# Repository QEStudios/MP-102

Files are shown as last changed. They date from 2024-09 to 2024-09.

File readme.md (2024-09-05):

# MP-102 Macropad

The MP-102 Macropad features 10 MX-compatible keys and 2 rotary encoders with optional buttons. It uses a Raspberry Pi Pico (RP2040) or compatible microcontroller as the brains. It can be constructed by anyone as long as you have a 3D printer.

## Ordering parts

The MP-102 was designed to be built on a budget of around $35 Australian Dollars. Thus, parts were aquired from less reliable places than where you might normally buy them. I've linked the relevant places here as well as in the `Layout and BOM.xlsx` file, but all of the parts are generic and can be bought from wherever you find easiest (or cheapest).

I ordered the Hot Melt Inserts from the link provided quite a while before I started this project, so I didn't personally factor this cost into the price of my own build of the MP-102.

[All prices in Australian Dollars]
| Item | Price | Link |
|---|---|---|
| 5pcs Rotary Encoder | $5.27 | https://www.aliexpress.com/item/1005003070250718.html |
| 10pcs Keycaps | $4.17 | https://www.aliexpress.com/item/1005005825113345.html |
| 10pcs Key Switches | $4.61 | https://www.aliexpress.com/item/1005006376024657.html |
| Raspberry Pi Pico | $4.32 | https://www.aliexpress.com/item/1005006293406528.html |
| 10pcs Hotswap Sockets | $2.65 | https://www.aliexpress.com/item/1005006737039916.html |
| M2 OD3.5 Holt Melt Inserts | $5.93 | https://www.aliexpress.com/item/1005006465779940.html |
| USB C Cable | $2.39 | https://www.aliexpress.com/item/1005006065386047.html |
| PCB | $5.20 | https://jlcpcb.com/ |

## Build Instructions

### 3D Prints

All 3D model files can be found in the `3D Models` folder in this repository.

You might want to first print out `USB C Test Piece.stl` and make sure that your USB cable fits through the hole, as this is the size of the opening to the USB C port on the Pico.

There are two different files for the knobs, one with 0.1mm tolerences and one with 0.2mm tolerences. I recommend printing both and choosing the one which fits better for you. You can also use the horizontal expansion setting in your slicer to fine-tune this to your liking.

All files (excluding `USC C Test Piece.stl`) need to be printed only once, apart from the knob file (either `Knob 0.1mm Clearance.stl` or `Knob 0.2mm Clearance.stl`), which you need to print 2 of.

The top part of the case should slide onto the bottom part of the case. You'll need to insert the hot melt inserts into the two holes on the underside of the top part of the case. 

### PCB

The PCB was designed in KiCad, and the project files for the PCB can be found in the `PCB` folder in this repository.

The gerber files have been included in the `PCB/gerbers` folder, but your mileage may vary when using them. I recommend re-generating the gerbers yourself, just to be safe.

I ordered the PCBs from JLCPCB due to their very low price and shipping costs, but you can use whichever fab house you prefer.

Make sure to order the PCB with a thickness of 1.6mm as the case was designed for a PCB of that size.

### Flashing the Pico

1. Install QMK by following [this guide](https://docs.qmk.fm/newbs_getting_started).
2. Copy the `QMK Definition` folder into your QMK `keyboards` directory, and rename the `QMK Definition` folder to `mp102`.
3. Run `qmk flash -kb mp102 -km default` in the QMK MSYS terminal. When it says it's waiting for the device, plug the Pico into your computer while holding the BOOT button down. QMK should flash the Pico with the correct firmware.

### Assembly

1. Solder all the components onto the PCB. Make sure that the Pico is soldered onto the **underside** of the PCB.
2. Click the keyswitches into the plate. The top 2 rows should be oriented facing upwards (with the pins on the bottom), and the lower row of 2 switches should be oriented facing downwards (with the pins on the top). If you're using keycaps that let you customise their legends, now is a good time to do that.

# TODO: finish documentation

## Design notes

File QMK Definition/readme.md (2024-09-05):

# mp102

mp102

*A short description of the keyboard/project*

* Keyboard Maintainer: [SKM GEEK](https://github.com/QEStudios)
* Hardware Supported: *The PCBs, controllers supported*
* Hardware Availability: *Links to where you can find this hardware*

Make example for this keyboard (after setting up your build environment):

    make mp102:default

Flashing example for this keyboard:

    make mp102:default:flash

See the [build environment setup](https://docs.qmk.fm/#/getting_started_build_tools) and the [make instructions](https://docs.qmk.fm/#/getting_started_make_guide) for more information. Brand new to QMK? Start with our [Complete Newbs Guide](https://docs.qmk.fm/#/newbs).

## Bootloader

Enter the bootloader in 3 ways:

* **Bootmagic reset**: Hold down the key at (0,0) in the matrix (usually the top left key or Escape) and plug in the keyboard
* **Physical reset button**: Briefly press the button on the back of the PCB - some may have pads you must short instead
* **Keycode in layout**: Press the key mapped to `QK_BOOT` if it is available

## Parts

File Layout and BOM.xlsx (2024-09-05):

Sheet: Costs
Item | Price | Link
5pcs Rotary Encoder | $5.27 | https://www.aliexpress.com/item/1005003070250718.html
10pcs Keycaps | $4.17 | https://www.aliexpress.com/item/1005005825113345.html
10pcs Key Switches | $4.61 | https://www.aliexpress.com/item/1005006376024657.html
Raspberry Pi Pico | $4.32 | https://www.aliexpress.com/item/1005006293406528.html
10pcs Hotswap Sockets | $2.65 | https://www.aliexpress.com/item/1005006737039916.html
USB C Cable | $2.39 | https://www.aliexpress.com/item/1005006065386047.html
PCB | $5.20 | https://jlcpcb.com/
Total | $28.61
Budget | $30.00
Budget Difference | $1.39

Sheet: Layout
Vol |  |  | Custom
Firefox | Files | Discord | Maximise
Tab Left | Tab Right | Screen Shot | Deafen
 | Alt | Mute

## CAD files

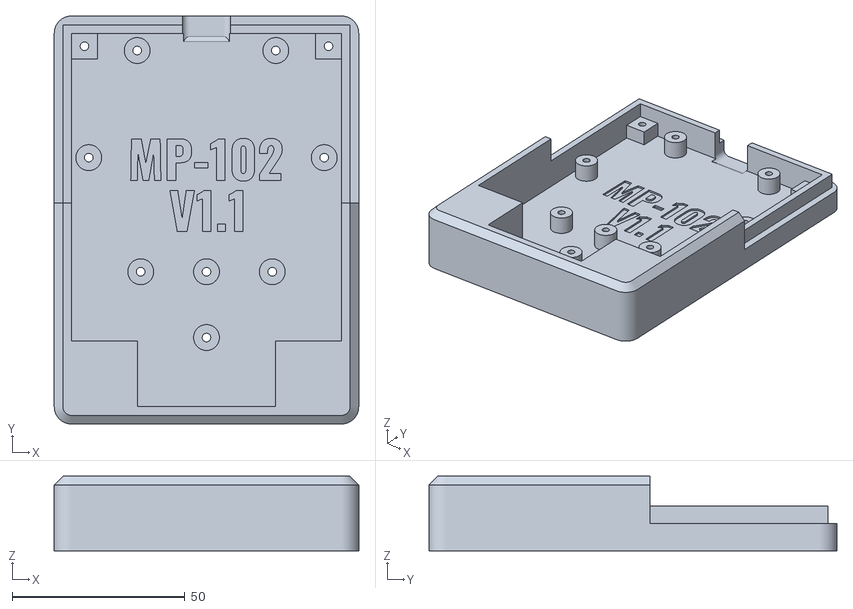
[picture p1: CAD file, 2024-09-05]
3D Models/Case Bottom.stl
88.2 x 118.2 x 21.6

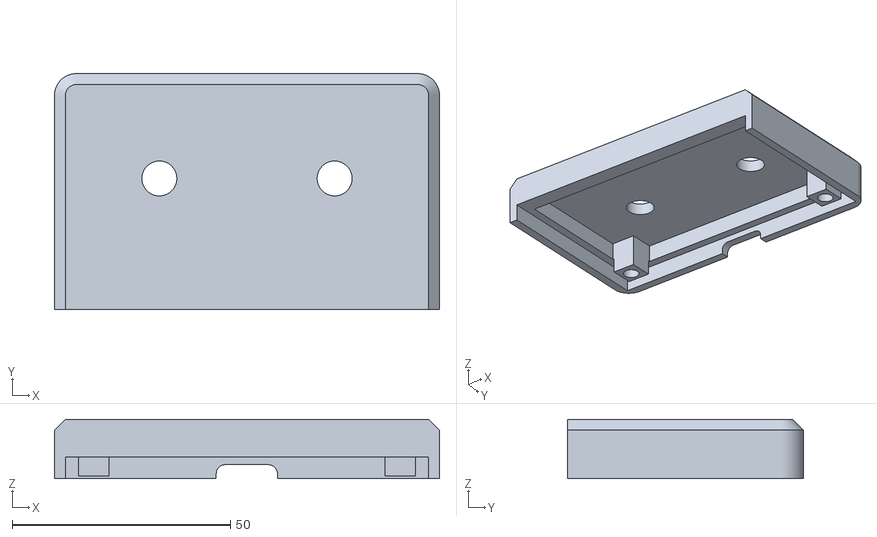
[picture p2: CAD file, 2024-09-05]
3D Models/Case Top.stl
88.2 x 54.0 x 13.6

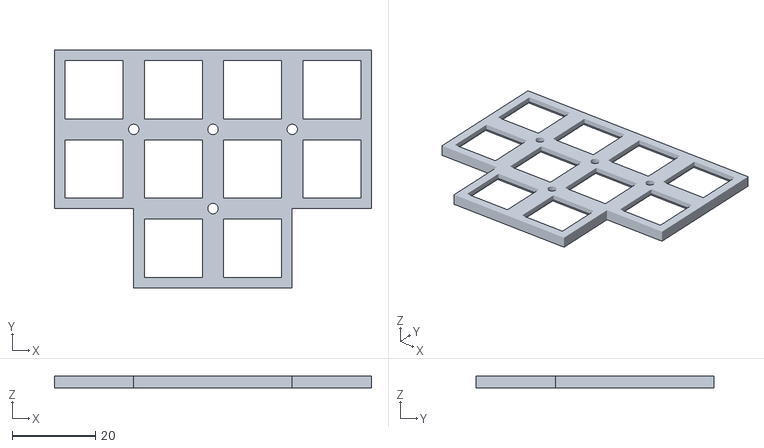
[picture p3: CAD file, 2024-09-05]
3D Models/Plate.stl
76.2 x 57.1 x 3.00

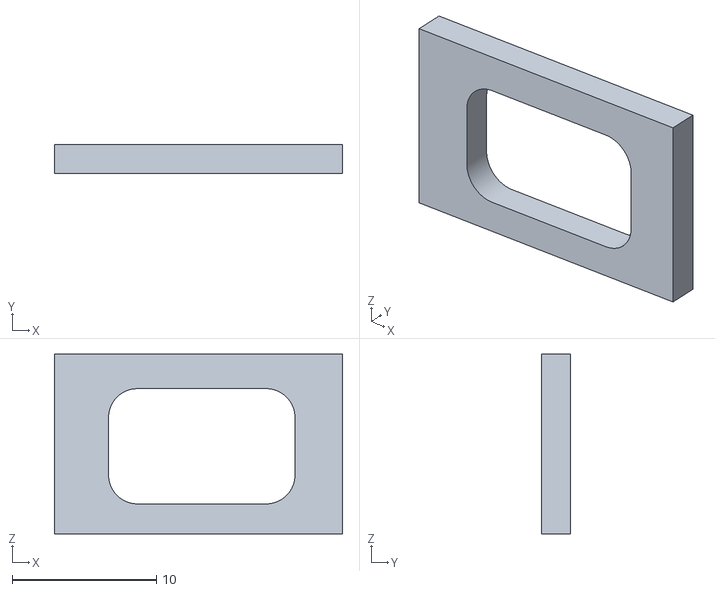
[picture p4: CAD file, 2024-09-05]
3D Models/USB C Test Piece.stl
20.0 x 2.00 x 12.5

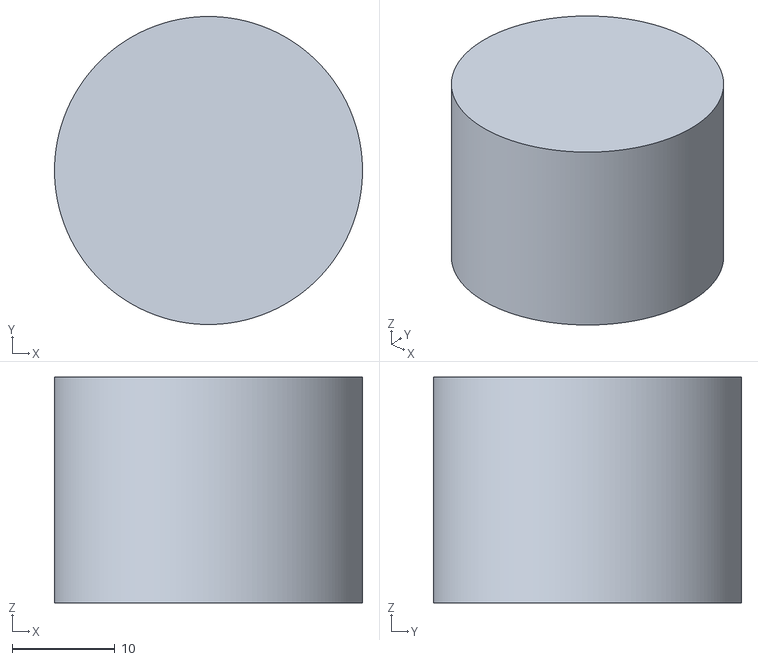
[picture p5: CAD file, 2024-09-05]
3D Models/Knob 0.1mm Clearance.stl
30.0 x 30.0 x 22.0

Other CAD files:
3D Models/Knob 0.2mm Clearance.stl
Plate.dxf

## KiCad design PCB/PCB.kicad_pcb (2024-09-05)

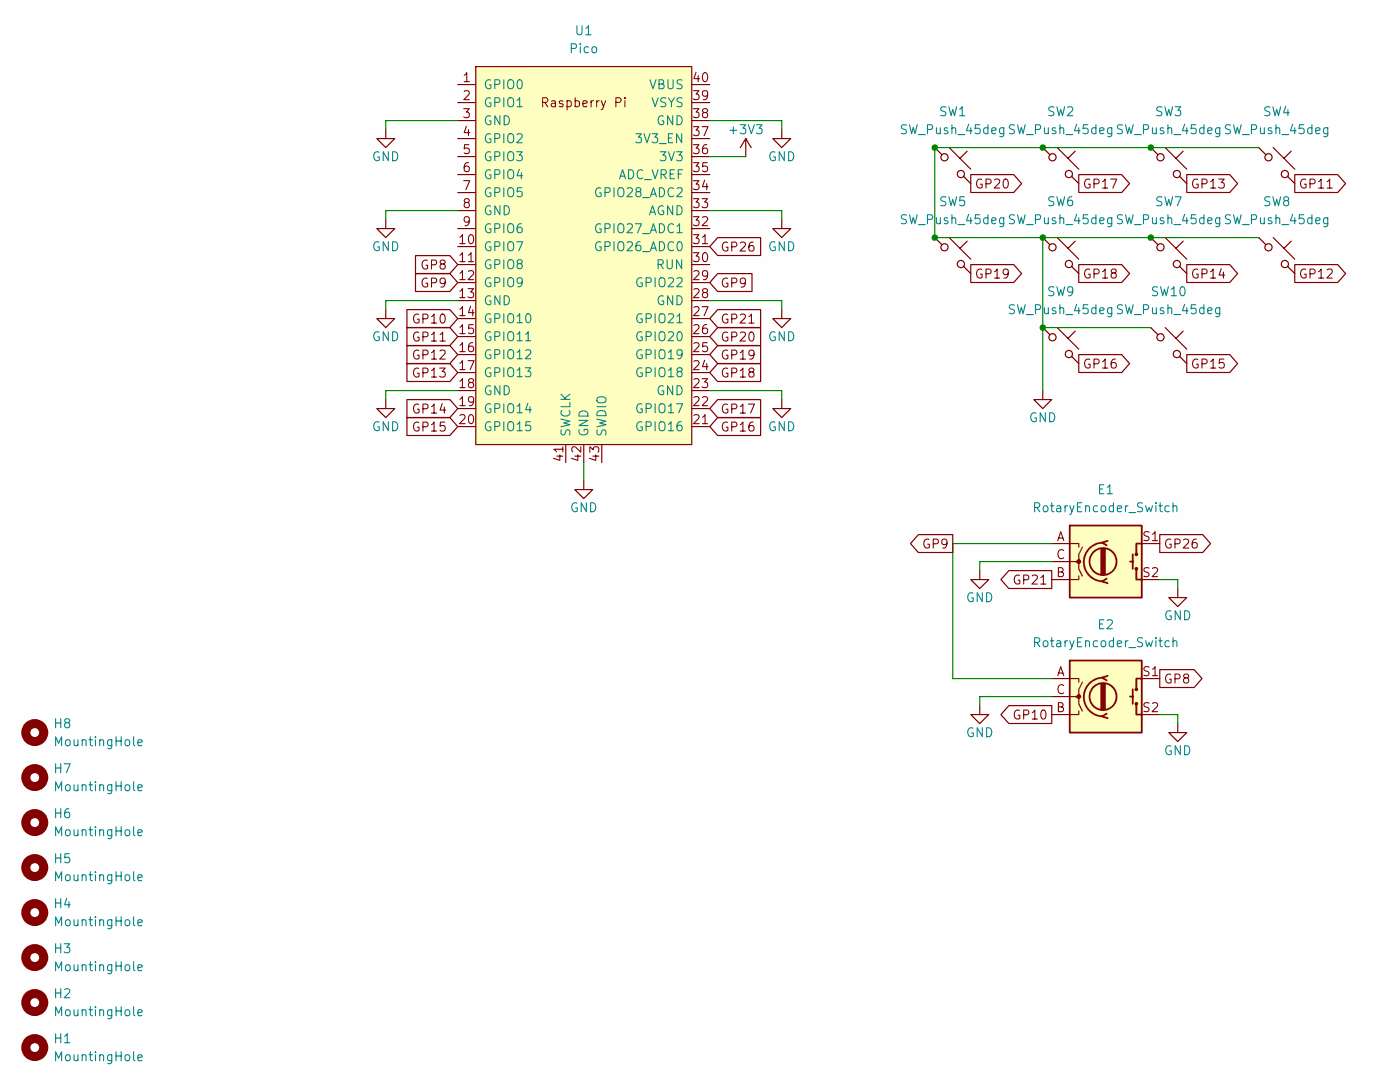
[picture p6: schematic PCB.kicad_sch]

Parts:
E1, E2: RotaryEncoder_Switch; RotaryEncoder_Alps_EC12E-Switch_Vertical_H20mm
H1, H2, H3, H4, H5, H6, H7, H8: MountingHole; MountingHole_2.2mm_M2
SW1, SW2, SW3, SW4, SW5, SW6, SW7, SW8, SW9, SW10: SW_Push_45deg; SW_Hotswap_Kailh_MX_1.00u
U1: Pico; RPi_Pico_SMD_TH

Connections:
+3V3: U1.36 (3V3)
GND: E1.C, E1.S2, E2.C, E2.S2, SW1.1, SW2.1, SW3.1, SW4.1, SW5.1, SW6.1, SW7.1, SW8.1, SW9.1, SW10.1, U1.3 (GND), U1.8 (GND), U1.13 (GND), U1.18 (GND), U1.23 (GND), U1.28 (GND), U1.33 (AGND), U1.38 (GND), U1.42 (GND)
GP8: E2.S1, U1.11 (GPIO8)
GP9: E1.A, E2.A, U1.12 (GPIO9), U1.29 (GPIO22)
GP10: E2.B, U1.14 (GPIO10)
GP11: SW4.2, U1.15 (GPIO11)
GP12: SW8.2, U1.16 (GPIO12)
GP13: SW3.2, U1.17 (GPIO13)
GP14: SW7.2, U1.19 (GPIO14)
GP15: SW10.2, U1.20 (GPIO15)
GP16: SW9.2, U1.21 (GPIO16)
GP17: SW2.2, U1.22 (GPIO17)
GP18: SW6.2, U1.24 (GPIO18)
GP19: SW5.2, U1.25 (GPIO19)
GP20: SW1.2, U1.26 (GPIO20)
GP21: E1.B, U1.27 (GPIO21)
GP26: E1.S1, U1.31 (GPIO26_ADC0)

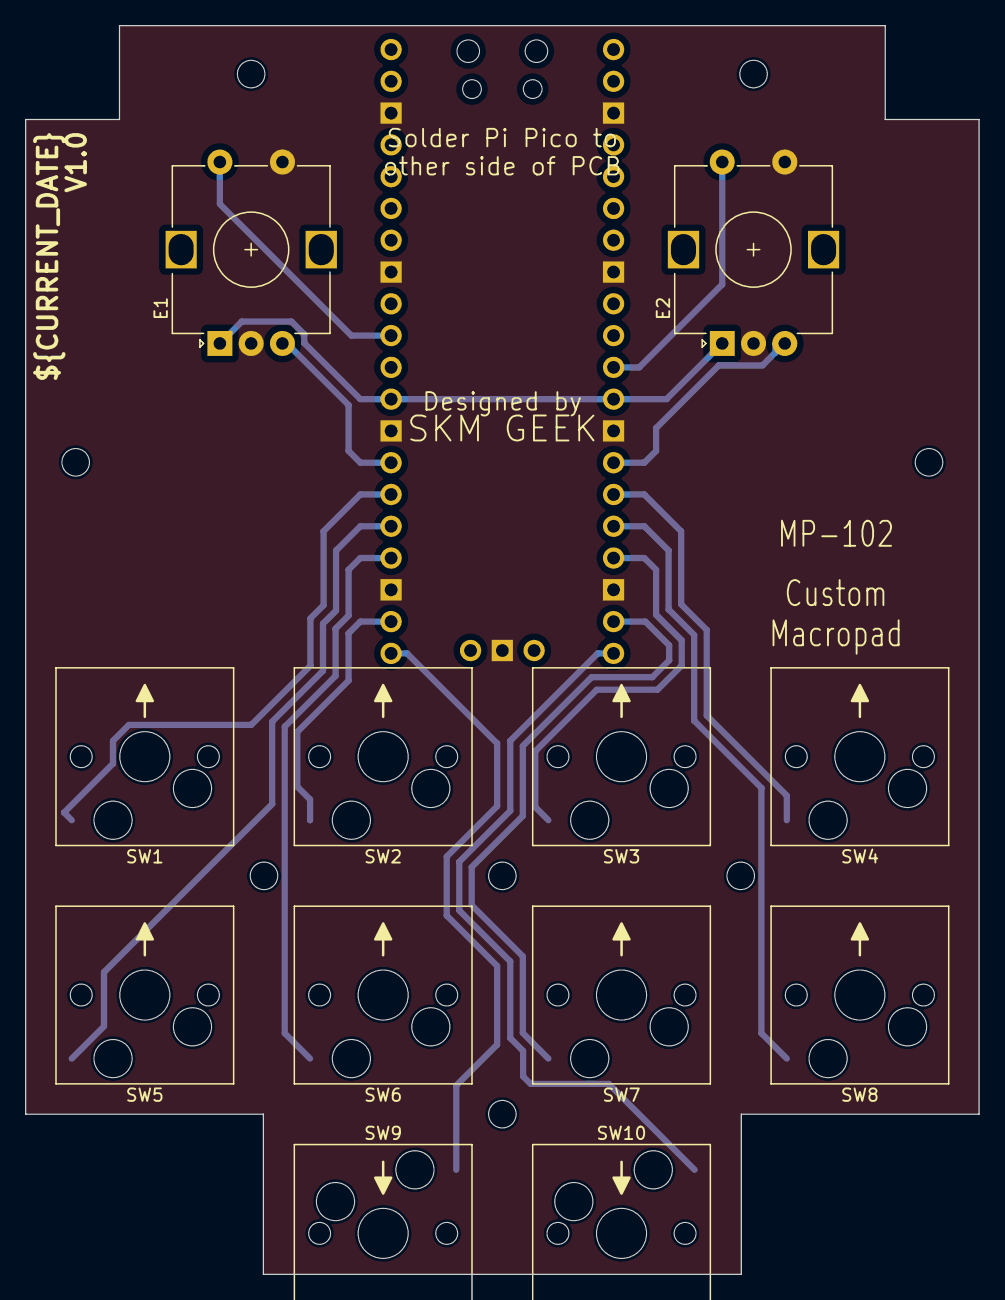
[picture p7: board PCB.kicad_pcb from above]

Board: 2 copper layers, 76.2 x 99.8 mm, 21 parts (1 on the bottom side), 16 nets.

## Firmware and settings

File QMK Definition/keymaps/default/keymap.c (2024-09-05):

// Copyright 2023 QMK
// SPDX-License-Identifier: GPL-2.0-or-later

#include QMK_KEYBOARD_H

const uint16_t PROGMEM keymaps[][MATRIX_ROWS][MATRIX_COLS] = {
    /*
     * ┌─────┬─────┬─────┬─────┐
     * │ F13 │ F14 │ F15 │ F16 │
     * ├─────┼─────┼─────┼─────┤
     * │ F17 │ F18 │ F19 │ F20 │
     * └─────┼─────┼─────┼─────┘
     *  (F23)│ F21 │ F22 │(F24)
     *       └─────┴─────┘
     */
    [0] = LAYOUT_ortho_4x3(
        KC_F13,   KC_F14,   KC_F15,   KC_F16,
        KC_F17,   KC_F18,   KC_F19,   KC_F20,
        KC_F23,   KC_F21,   KC_F22,   KC_F24
    )
};

#if defined(ENCODER_MAP_ENABLE)
const uint16_t PROGMEM encoder_map[][NUM_ENCODERS][NUM_DIRECTIONS] = {
    [0] = { ENCODER_CCW_CW(MS_WHLU, MS_WHLD),  ENCODER_CCW_CW(KC_VOLD, KC_VOLU)  },
};
#endif

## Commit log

2024-09-05 Update information
    [Case Bottom.stl, Layout and BOM.xlsx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]
2024-09-05 PCB thickness note
